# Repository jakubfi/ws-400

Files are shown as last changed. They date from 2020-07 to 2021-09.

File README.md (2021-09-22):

WS-400 is a device that connects to any of MERA-400 debug interfaces to display internal CPU and AWP states. You can see it in action [here](https://www.youtube.com/watch?v=3XAOpLWKt_o)

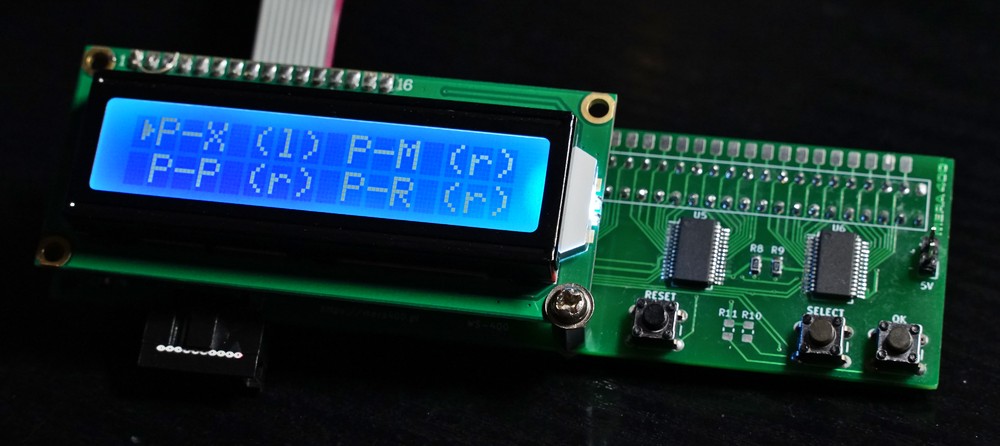
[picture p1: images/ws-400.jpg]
WS-400


After powering the device on, user selects the debug interface which WS-400 is connected to with *SELECT* button. Available connections are:

* **CPU**: P-X (l), P-M (r), P-P (r), P-R (r), P-A (l),
* **AWP**: FPA (l) FPA (r), FPM (l), FPM (r), FPS (l).

Connector location (either left or right) is denoted in parentheses. Selection is confirmed with *OK* button and WS-400 immediately starts displaying active signals. If all active signals don't fit on the screen, right pointing arrow appears on the bottom right. *SELECT* button can then be used to switch to next portion of active signals.

User can also switch to raw display mode at any time with *OK* button. In this mode *SELECT* button allows switching between 16-bit portions of the interface view.

Device can also be installed on the interface rotated 180 degrees in Z axis. This requires translation of signal, which is achieved by powering on or resetting the device with button *OK* pressed.

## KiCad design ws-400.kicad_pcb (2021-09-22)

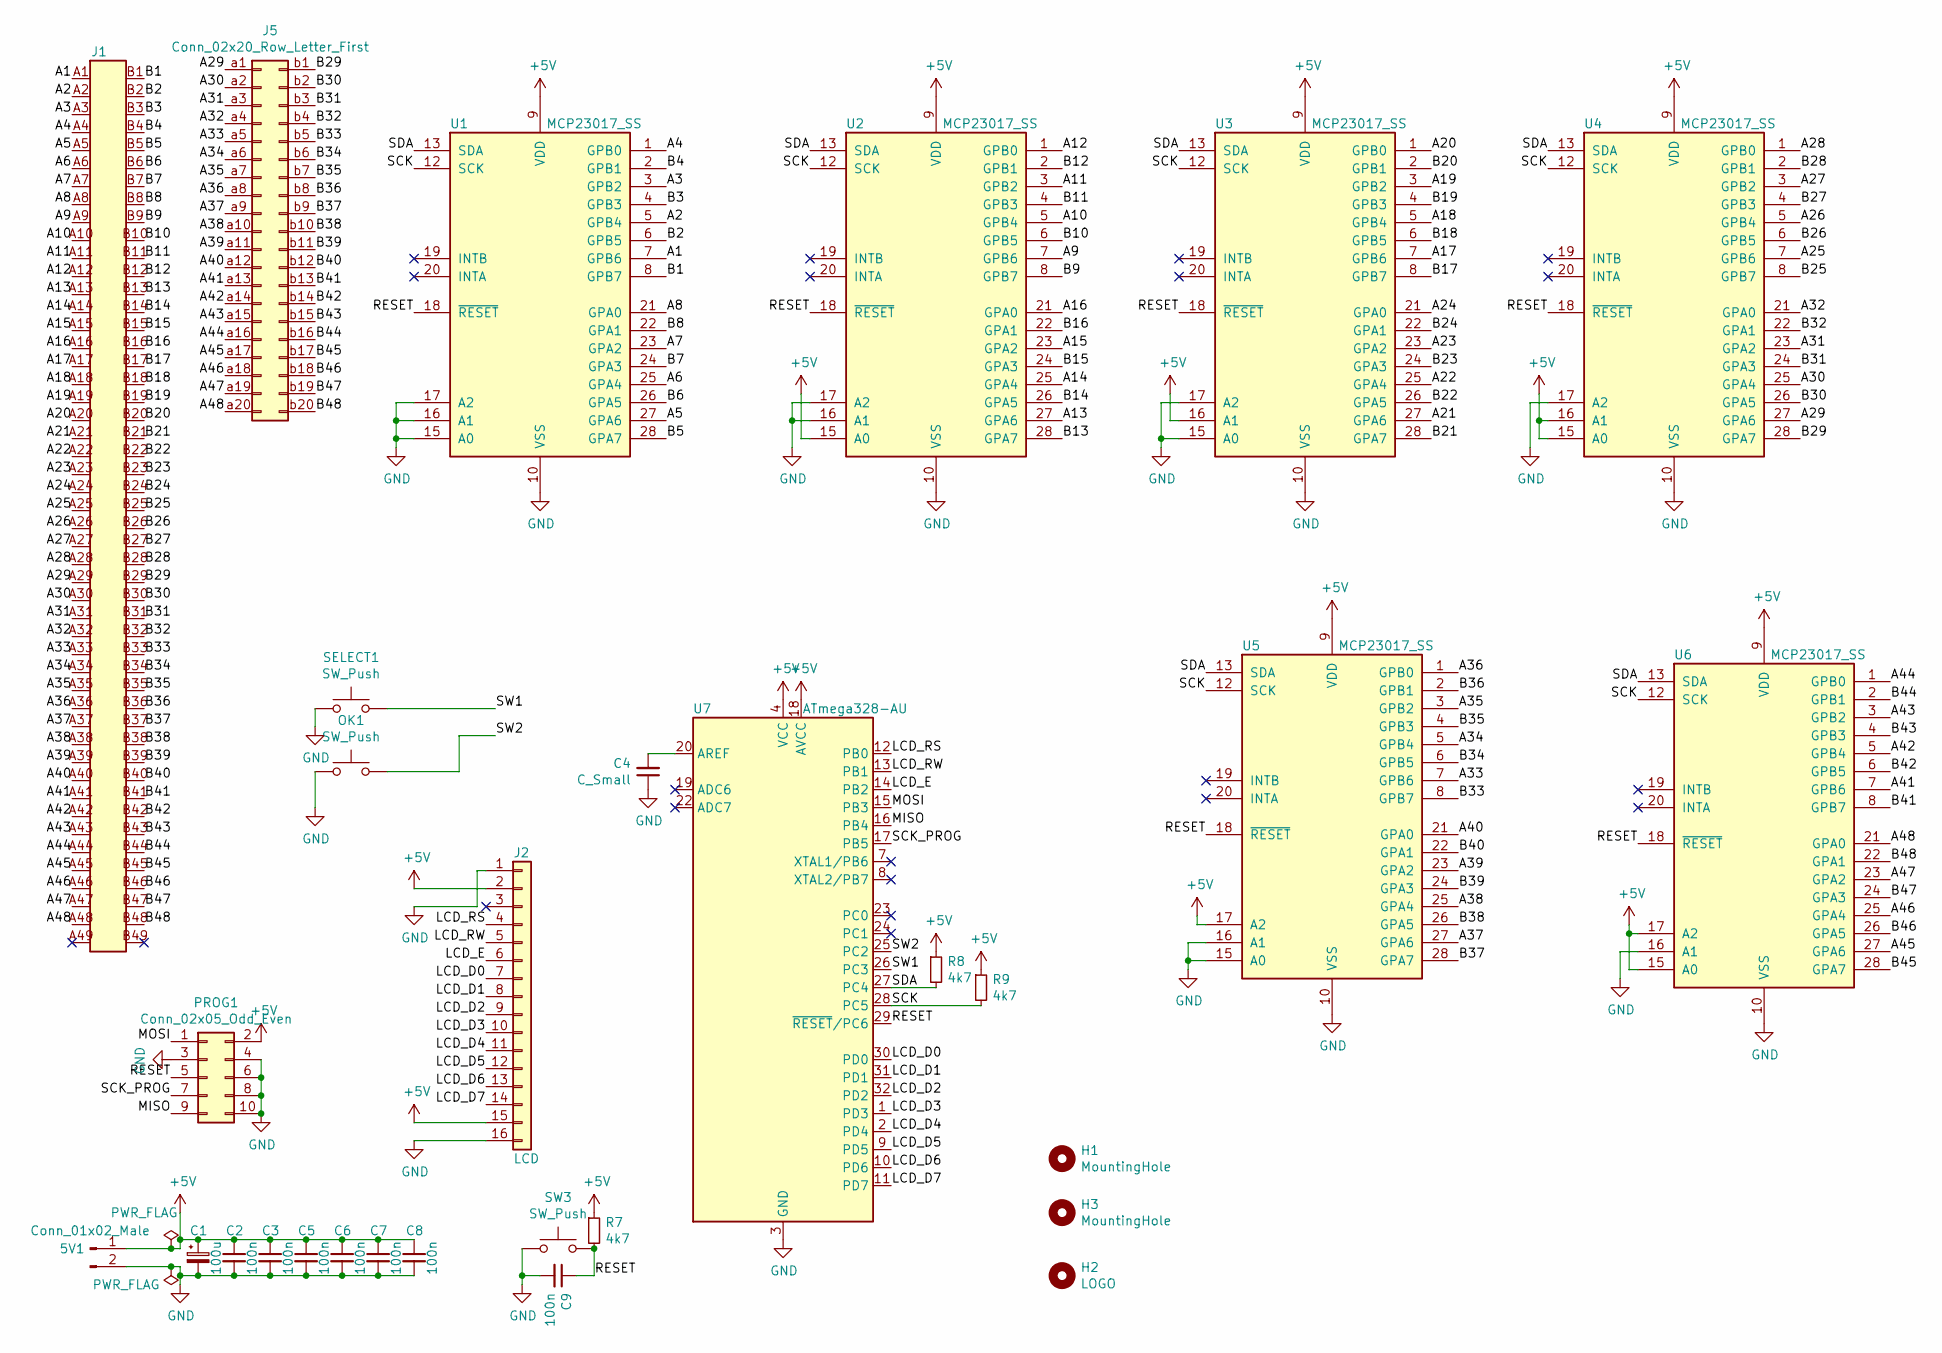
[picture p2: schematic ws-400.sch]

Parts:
5V1: Conn_01x02_Male; PinHeader_1x02_P2.54mm_Vertical
C1: 100u; CP_EIA-3528-21_Kemet-B_Pad1.50x2.35mm_HandSolder
C2, C3, C5, C6, C7, C8, C9: 100n; C_0805_2012Metric_Pad1.15x1.40mm_HandSolder
C4: C_Small; C_0805_2012Metric_Pad1.15x1.40mm_HandSolder
H1, H3: MountingHole; MountingHole_3mm
H2: LOGO; MERA400_LOGO_FCU_MEDIUM
J1: Conn_02x49; ELTRA801+
J2: LCD; PinHeader_1x16_P2.54mm_Vertical
J5: Conn_02x20_Row_Letter_First; 40pin_edge
OK1: SW_Push; SW_PUSH_6mm
PROG1: Conn_02x05_Odd_Even; PinHeader_2x05_P2.54mm_Vertical
R7, R8, R9: 4k7; R_0805_2012Metric_Pad1.15x1.40mm_HandSolder
SELECT1: SW_Push; SW_PUSH_6mm
SW3: SW_Push; SW_PUSH_6mm
U1, U2, U3, U4, U5, U6: MCP23017_SS; SSOP-28_5.3x10.2mm_P0.65mm
U7: ATmega328-AU; TQFP-32_7x7mm_P0.8mm

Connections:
+5V: 5V1.1, C1.1, C2.1, C3.1, C5.1, C6.1, C7.1, C8.1, J2.2, J2.15, PROG1.2, R7.1, R8.1, R9.1, U1.9 (VDD), U2.9 (VDD), U2.15 (A0), U3.9 (VDD), U3.16 (A1), U4.9 (VDD), U4.15 (A0), U4.16 (A1), U5.9 (VDD), U5.17 (A2), U6.9 (VDD), U6.15 (A0), U6.17 (A2), U7.4 (VCC), U7.6 (VCC), U7.18 (AVCC)
/A1: J1.A1, U1.7 (GPB6)
/A2: J1.A2, U1.5 (GPB4)
/A3: J1.A3, U1.3 (GPB2)
/A4: J1.A4, U1.1 (GPB0)
/A5: J1.A5, U1.27 (GPA6)
/A6: J1.A6, U1.25 (GPA4)
/A7: J1.A7, U1.23 (GPA2)
/A8: J1.A8, U1.21 (GPA0)
/A9: J1.A9, U2.7 (GPB6)
/A10: J1.A10, U2.5 (GPB4)
/A11: J1.A11, U2.3 (GPB2)
/A12: J1.A12, U2.1 (GPB0)
/A13: J1.A13, U2.27 (GPA6)
/A14: J1.A14, U2.25 (GPA4)
/A15: J1.A15, U2.23 (GPA2)
/A16: J1.A16, U2.21 (GPA0)
/A17: J1.A17, U3.7 (GPB6)
/A18: J1.A18, U3.5 (GPB4)
/A19: J1.A19, U3.3 (GPB2)
/A20: J1.A20, U3.1 (GPB0)
/A21: J1.A21, U3.27 (GPA6)
/A22: J1.A22, U3.25 (GPA4)
/A23: J1.A23, U3.23 (GPA2)
/A24: J1.A24, U3.21 (GPA0)
/A25: J1.A25, U4.7 (GPB6)
/A26: J1.A26, U4.5 (GPB4)
/A27: J1.A27, U4.3 (GPB2)
/A28: J1.A28, U4.1 (GPB0)
/A29: J1.A29, J5.a1, U4.27 (GPA6)
/A30: J1.A30, J5.a2, U4.25 (GPA4)
/A31: J1.A31, J5.a3, U4.23 (GPA2)
/A32: J1.A32, J5.a4, U4.21 (GPA0)
/A33: J1.A33, J5.a5, U5.7 (GPB6)
/A34: J1.A34, J5.a6, U5.5 (GPB4)
/A35: J1.A35, J5.a7, U5.3 (GPB2)
/A36: J1.A36, J5.a8, U5.1 (GPB0)
/A37: J1.A37, J5.a9, U5.27 (GPA6)
/A38: J1.A38, J5.a10, U5.25 (GPA4)
/A39: J1.A39, J5.a11, U5.23 (GPA2)
/A40: J1.A40, J5.a12, U5.21 (GPA0)
/A41: J1.A41, J5.a13, U6.7 (GPB6)
/A42: J1.A42, J5.a14, U6.5 (GPB4)
/A43: J1.A43, J5.a15, U6.3 (GPB2)
/A44: J1.A44, J5.a16, U6.1 (GPB0)
/A45: J1.A45, J5.a17, U6.27 (GPA6)
/A46: J1.A46, J5.a18, U6.25 (GPA4)
/A47: J1.A47, J5.a19, U6.23 (GPA2)
/A48: J1.A48, J5.a20, U6.21 (GPA0)
/B1: J1.B1, U1.8 (GPB7)
/B2: J1.B2, U1.6 (GPB5)
/B3: J1.B3, U1.4 (GPB3)
/B4: J1.B4, U1.2 (GPB1)
/B5: J1.B5, U1.28 (GPA7)
/B6: J1.B6, U1.26 (GPA5)
/B7: J1.B7, U1.24 (GPA3)
/B8: J1.B8, U1.22 (GPA1)
/B9: J1.B9, U2.8 (GPB7)
/B10: J1.B10, U2.6 (GPB5)
/B11: J1.B11, U2.4 (GPB3)
/B12: J1.B12, U2.2 (GPB1)
/B13: J1.B13, U2.28 (GPA7)
/B14: J1.B14, U2.26 (GPA5)
/B15: J1.B15, U2.24 (GPA3)
/B16: J1.B16, U2.22 (GPA1)
/B17: J1.B17, U3.8 (GPB7)
/B18: J1.B18, U3.6 (GPB5)
/B19: J1.B19, U3.4 (GPB3)
/B20: J1.B20, U3.2 (GPB1)
/B21: J1.B21, U3.28 (GPA7)
/B22: J1.B22, U3.26 (GPA5)
/B23: J1.B23, U3.24 (GPA3)
/B24: J1.B24, U3.22 (GPA1)
/B25: J1.B25, U4.8 (GPB7)
/B26: J1.B26, U4.6 (GPB5)
/B27: J1.B27, U4.4 (GPB3)
/B28: J1.B28, U4.2 (GPB1)
/B29: J1.B29, J5.b1, U4.28 (GPA7)
/B30: J1.B30, J5.b2, U4.26 (GPA5)
/B31: J1.B31, J5.b3, U4.24 (GPA3)
/B32: J1.B32, J5.b4, U4.22 (GPA1)
/B33: J1.B33, J5.b5, U5.8 (GPB7)
/B34: J1.B34, J5.b6, U5.6 (GPB5)
/B35: J1.B35, J5.b7, U5.4 (GPB3)
/B36: J1.B36, J5.b8, U5.2 (GPB1)
/B37: J1.B37, J5.b9, U5.28 (GPA7)
/B38: J1.B38, J5.b10, U5.26 (GPA5)
/B39: J1.B39, J5.b11, U5.24 (GPA3)
/B40: J1.B40, J5.b12, U5.22 (GPA1)
/B41: J1.B41, J5.b13, U6.8 (GPB7)
/B42: J1.B42, J5.b14, U6.6 (GPB5)
/B43: J1.B43, J5.b15, U6.4 (GPB3)
/B44: J1.B44, J5.b16, U6.2 (GPB1)
/B45: J1.B45, J5.b17, U6.28 (GPA7)
/B46: J1.B46, J5.b18, U6.26 (GPA5)
/B47: J1.B47, J5.b19, U6.24 (GPA3)
/B48: J1.B48, J5.b20, U6.22 (GPA1)
/LCD_D0: J2.7, U7.30 (PD0)
/LCD_D1: J2.8, U7.31 (PD1)
/LCD_D2: J2.9, U7.32 (PD2)
/LCD_D3: J2.10, U7.1 (PD3)
/LCD_D4: J2.11, U7.2 (PD4)
/LCD_D5: J2.12, U7.9 (PD5)
/LCD_D6: J2.13, U7.10 (PD6)
/LCD_D7: J2.14, U7.11 (PD7)
/LCD_E: J2.6, U7.14 (PB2)
/LCD_RS: J2.4, U7.12 (PB0)
/LCD_RW: J2.5, U7.13 (PB1)
/MISO: PROG1.9, U7.16 (PB4)
/MOSI: PROG1.1, U7.15 (PB3)
/RESET: C9.1, PROG1.5, R7.2, SW3.2, U1.18 (~RESET~), U2.18 (~RESET~), U3.18 (~RESET~), U4.18 (~RESET~), U5.18 (~RESET~), U6.18 (~RESET~), U7.29 (~RESET~/PC6)
/SCK: R9.2, U1.12 (SCK), U2.12 (SCK), U3.12 (SCK), U4.12 (SCK), U5.12 (SCK), U6.12 (SCK), U7.28 (PC5)
/SCK_PROG: PROG1.7, U7.17 (PB5)
/SDA: R8.2, U1.13 (SDA), U2.13 (SDA), U3.13 (SDA), U4.13 (SDA), U5.13 (SDA), U6.13 (SDA), U7.27 (PC4)
/SW1: SELECT1.2, U7.26 (PC3)
/SW2: OK1.2, U7.25 (PC2)
GND: 5V1.2, C1.2, C2.2, C3.2, C4.1, C5.2, C6.2, C7.2, C8.2, C9.2, J2.1, J2.16, OK1.1, PROG1.3, PROG1.4, PROG1.6, PROG1.8, PROG1.10, SELECT1.1, SW3.1, U1.10 (VSS), U1.15 (A0), U1.16 (A1), U1.17 (A2), U2.10 (VSS), U2.16 (A1), U2.17 (A2), U3.10 (VSS), U3.15 (A0), U3.17 (A2), U4.10 (VSS), U4.17 (A2), U5.10 (VSS), U5.15 (A0), U5.16 (A1), U6.10 (VSS), U6.16 (A1), U7.3 (GND), U7.5 (GND), U7.21 (GND)
unnamed: C4.2, U7.20 (AREF)

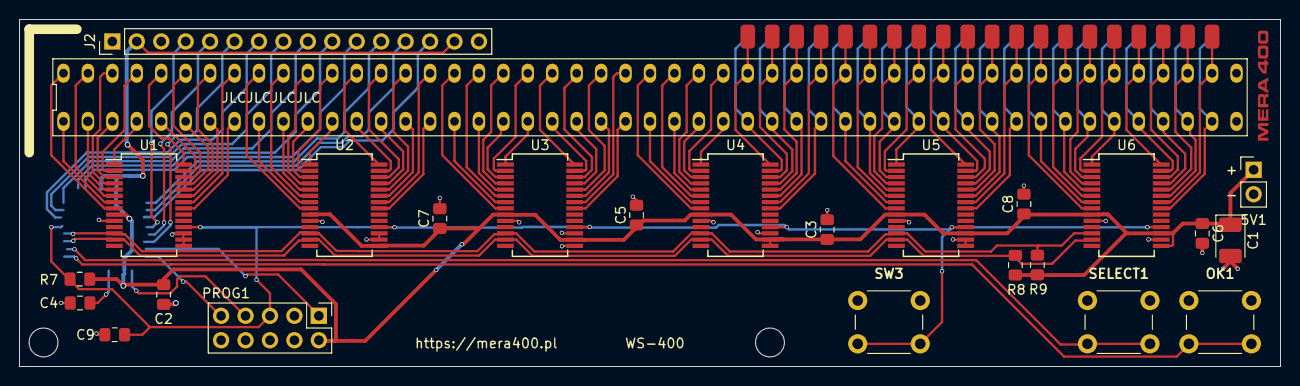
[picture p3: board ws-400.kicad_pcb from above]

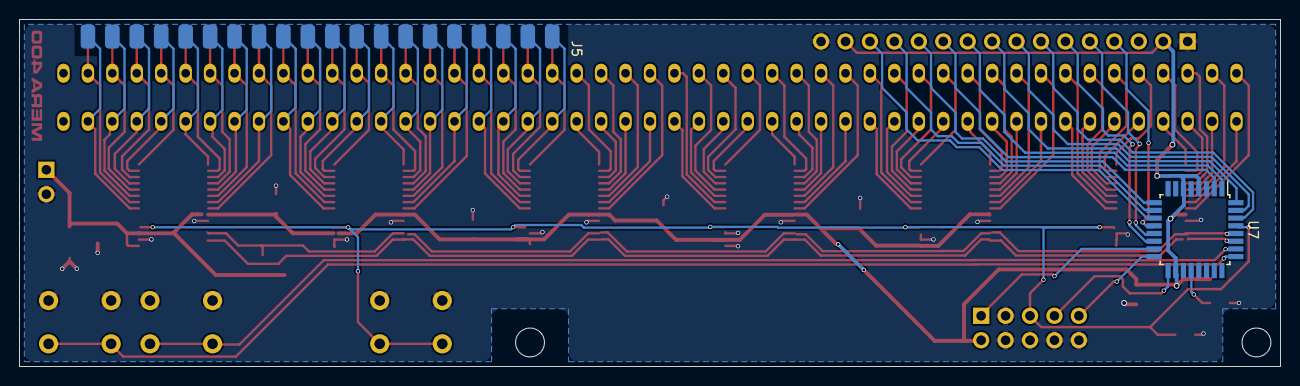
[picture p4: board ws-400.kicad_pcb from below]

Board: 2 copper layers, 131.1 x 36.1 mm, 30 parts (2 on the bottom side), 118 nets.

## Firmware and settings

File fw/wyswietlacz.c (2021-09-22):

#include <stdint.h>
#include <stdlib.h>
#include <stddef.h>
#include <stdio.h>
#include <string.h>
#include <avr/io.h>
#include <util/delay.h>
#include "hd44780.h"
#include "mcp23017.h"
#include "i2cmaster.h"
#include "chars.h"
#include "pins.h"
#include "scr.h"

#define SW_DIR	DDRC
#define SW_PORT	PORTC
#define SW_PIN	PINC
#define SW_SEL	(1 << PC3)
#define SW_OK	(1 << PC2)

MCP23017 dev[6];

/*
 * There are two debugger connectors per each module. This device can be connected to any one of them.
 * Each connector is a 96-pin edge connector. Pins are numbered from the right, starting from 1.
 * Top row is "D" row, bottom is "C". Right connector has pins 1 to 48, left - 49 to 96.
 *
 * Port expanders on the device are connected as follows:
 *
 *       1B7 1B5 1B3       6A5 6A3 6A1
 *     .-------------\   \------------.
 *     | D48 D47 D46 /   / D2  D1  D0 |
 *     | C48 C47 C46 \   \ C2  C1  C0 |
 *     `-------------/   /------------'
 *       1B6 1B4 1B2       6A4 6A2 6A0
 *
 * Note: "1B7" = expander U1, port B, bit 7
 *
 * When connecting the device to the left port, pin numbers 49-96 are remapped to 1-48
*/

uint8_t rotated = 0;
uint16_t raw_data[6];

// -----------------------------------------------------------------------
void update_state(void)
{
#ifdef SIMULATED
	static const uint16_t sim_data[6] = {
		0b0000000000000000,
		0b0000000000000000,
		0b0000000100000000,
		0b0000000010000000,
		0b0000000000000000,
		0b0000000000000000,
	};
	#endif

	for (uint8_t i=0 ; i<6 ; i++) {
#ifdef SIMULATED
		raw_data[i] = sim_data[i];
#else
		raw_data[i]  = mcp23017_read_register(dev+i, MCP23017_GPIOB) << 8;
		raw_data[i] |= mcp23017_read_register(dev+i, MCP23017_GPIOA);
#endif
	}
}

// -----------------------------------------------------------------------
uint8_t read_signal(uint8_t row, uint8_t column)
{
	// Device connects to either right (pins 1-48) or left (pins 49-96) debug connector.
	// Translate row numbers to 1-48 for the left connector.
	if (column > 48) column = column - 48;

	// Pins are numbered right to left, 1 to 48. Bits are stored left to right.
	// Column numbers need to be swapped and reindexed: 1..48 -> 47..0
	column = 48 - column;

	// Translate row and column if the device is rotated.
	if (rotated) {
		column = 47 - column; // first column becomes last
		row = 1 - row; // top row becomes bottom
	}

	// Each word holds 8 columns of data
	const uint8_t word = column / 8;
	// 2 bits per column, 16 bits per word
	// upper row holds even bits (with no rotation)
	const uint8_t bit = 15 - (2 * (column % 8) + row);

	return (raw_data[word] >> bit) & 1;
}

// -----------------------------------------------------------------------
uint8_t read_signal_rowcol(uint8_t rowcol)
{
	const uint8_t row = rowcol >> 7;
	const uint8_t col = rowcol & 0b01111111;

	return read_signal(row, col);
}


// -----------------------------------------------------------------------
void print_raw(uint8_t pos)
{
	const int8_t columns = 8;
	const int8_t start = 1 + columns * pos;
	const int8_t end = start + columns;
	char s[12];

	scr_clr();

	sprintf(s, "%d-%d", end-1, start);
	scr_print_at(11, 0, " pos");
	scr_print_at(11, 1, s);
	scr_put_at(10, 0, CH_VDOT);
	scr_put_at(10, 1, CH_VDOT);

	uint8_t xpos = 8;
	for (uint8_t column=start ; column<end ; column++) {
		for (uint8_t row=ROW_D ; row<=ROW_C ; row++) {
			const uint8_t val = '0' + read_signal(row, column);
			scr_put_at(xpos, row, val);
		}
		xpos--;
		if (xpos == 4) xpos--; // additional space between nibbles
	}
}

// -----------------------------------------------------------------------
char * decimalize(const __flash struct signal *s, char *tmp, uint8_t polarity)
{
	int8_t *x = (int8_t*) s->d.reg;
	// Value may require shifting left if it is a part of larger register.
	// Shift is stored in the attributes.
	const uint8_t shift = (s->attr & SIG_SHIFT_MASK) >> SIG_SHIFT_POS;

	uint16_t val = 0;
	while (*x != 0) {
		val <<= 1;
		if (read_signal_rowcol(*x) == polarity) val |= 1;
		x++;
	}

	sprintf(tmp, "%s=%ld", s->name, ((uint32_t)val) << shift);

	return tmp;
}

// -----------------------------------------------------------------------
int smart_print(char *str)
{
	if (!str) return 0;

	const uint8_t len = strlen(str);
	if (sx+len > LCD_COLS-sy) { // -sy to make space for CH_CONT at line 1
		if (sy >= 1) {
			scr_put_at(15, 1, CH_CONT);
			return 1;
		} else {
			scr_setpos(0, 1);
		}
	}

	scr_print(str);
	if ((sx > 0) && (sx < LCD_COLS)) {
		scr_print(" ");
	}
	return 0;
}

// -----------------------------------------------------------------------
const struct signal * print_state(const __flash struct signal *s)
{
	char *str;
	char tmp[16];
	uint8_t no_fit = 0;

	scr_clr();

	while (s->name) {
		const uint8_t sig_polarity = s->attr & SIG_POLARITY_MASK;
		const uint8_t sig_type = s->attr & SIG_TYPE_MASK;

		str = NULL;
		if (sig_type == BIN) {
			if (read_signal_rowcol(s->d.rowcol) == sig_polarity) str = (char *) s->name;
		} else if (sig_type == DEC) {
			str = decimalize(s, tmp, sig_polarity);
		}

		no_fit = smart_print(str);
		if (no_fit) {
			break;
		} else {
			s++;
		}
	}

	if (!s->name) s = NULL;

	return s;
}

// -----------------------------------------------------------------------
void menu_update(uint8_t pos)
{
	static uint8_t last_pos = 99;
	if (last_pos == pos) return;
	last_pos = pos;

	static const char *conns[] = {
		" P-X (l)",
		" P-M (r)",
		" P-P (r)",
		" P-R (r)",
		" P-A (l)",
		" FPA (l)",
		" FPA (r)",
		" FPM (l)",
		" FPM (r)",
		" FPS (l)",
		"\x02\x02\x02\x02\x02\x02\x02\x02",
		"\x02\x02\x02\x02\x02\x02\x02\x02",
		NULL
	};

	const uint8_t start_p = 4*(pos / 4);
	const uint8_t end_p = start_p + 4;

	scr_clr();

	for (uint8_t i=start_p ; i<end_p ; i++) {
		scr_print(conns[i]);
	}

	const uint8_t cpos = pos % 4;
	scr_put_at(8*(cpos%2), cpos/2, CH_CURSOR);

	scr_blit();
}

// -----------------------------------------------------------------------
uint8_t key_pressed(uint8_t expected_key)
{
	uint8_t shift_reg = 0;
	int8_t repetitions = 0;

	do {
		shift_reg |= (SW_PIN & expected_key) ? 0 : 1;
		if ((repetitions == 0) && (shift_reg == 0)) {
			// no initial key press, nothing to do
			return 0;
		} else if (shift_reg == 0xff) {
			// got a key press
			return 1;
		} else {
			// press detected, start debouncing
			shift_reg <<= 1;
			repetitions++;
			_delay_ms(4);
		}
	} while (repetitions < 40);

	// no keypress after N repetitions
	return 0;
}

// -----------------------------------------------------------------------
void wait_no_key(void)
{
	while ((SW_PIN & (SW_SEL|SW_OK)) != (SW_SEL|SW_OK));
}

// -----------------------------------------------------------------------
const struct signal * select_connector()
{
	const uint8_t CONN_COUNT = 10;
	const struct signal *connections[] = { PX, PM, PP, PR, PA, FPAL, FPAR, FPML, FPMR, FPS };

	uint8_t pos = 0;

	menu_update(0);

	while (1) {
		if (key_pressed(SW_OK)) {
			wait_no_key();
			break;
		} else if (key_pressed(SW_SEL)) {
			pos++;
			if (pos >= CONN_COUNT) {
				pos = 0;
			}
			menu_update(pos);
			wait_no_key();
		}
	}

	return connections[pos];
}

// -----------------------------------------------------------------------
void setup()
{
	// setup switches
	SW_DIR &= ~(SW_SEL|SW_OK);
	SW_PORT |= (SW_SEL|SW_OK);

	// setup MCP23017
	for (uint8_t i=0 ; i<6 ; i++) {
		mcp23017_init(dev+i, i);
		mcp23017_write_register(dev+i, MCP23017_IODIRA, 0xff);
		mcp23017_write_register(dev+i, MCP23017_IODIRB, 0xff);
		mcp23017_write_register(dev+i, MCP23017_IPOLA, 0);
		mcp23017_write_register(dev+i, MCP23017_IPOLB, 0);
		mcp23017_write_register(dev+i, MCP23017_GPPUA, 0);
		mcp23017_write_register(dev+i, MCP23017_GPPUB, 0);
	}

	// setup LCD
	lcd_init();
	lcd_cg_set(CH_CURSOR, cursor);
	lcd_cg_set(CH_HDOT, hdot);
	lcd_cg_set(CH_VDOT, vdot);
	lcd_cg_set(CH_CONT, cont);
	lcd_clear();
	lcd_home();
}

// -----------------------------------------------------------------------
int select_rotation(void)
{
	// If started with "OK" button pressed, assume display rotated 180 deg.
	if (!key_pressed(SW_OK)) return 0;

	scr_print_at(1, 0, ".-  DEVICE  <-.");
	scr_print_at(1, 1, "`>  ROTATED  -'");
	scr_blit();
	_delay_ms(500);
	wait_no_key();

	return 1;
}

// -----------------------------------------------------------------------
// ---- MAIN -------------------------------------------------------------
// -----------------------------------------------------------------------
int main(void)
{
	uint8_t raw = 0;
	uint8_t raw_pos = 0;
	uint8_t key_was_pressed = 0;
	const struct signal *selected_connector;
	const __flash struct signal *start_signal;
	const __flash struct signal *next_signal = NULL;

	setup();
	scr_clr();

	rotated = select_rotation();
	selected_connector = select_connector();
	start_signal = selected_connector;

	while (1) {
		// read debug bus state
		update_state();

		// Handle selecting next portion of signals (if they don't fit on the screen)
		if (key_pressed(SW_SEL)) {
			key_was_pressed = 1;
			if (raw) {
				raw_pos++;
				if (raw_pos>5) raw_pos = 0;
			} else {
				if (next_signal) start_signal = next_signal;
				else start_signal = selected_connector;
			}
		}

		// Pressing "OK" switches between raw and normal display
		if (key_pressed(SW_OK)) {
			key_was_pressed = 1;
			raw = ~raw;
			start_signal = selected_connector;
		}

		// Update screen immediatly after a key press for nice interactivity
		// (don't wait for key depress).
		if (raw) {
			print_raw(raw_pos);
		} else {
			next_signal = print_state(start_signal);
		}
		scr_blit();

		// Wait for key depress only if a key was pressed in current loop
		// so we don't wait if a key was pressed during screen update.
		// That's to avoid ghost presses.
		if (key_was_pressed) {
			key_was_pressed = 0;
			wait_no_key();
		}
	}
}

// vim: tabstop=4 shiftwidth=4 autoindent

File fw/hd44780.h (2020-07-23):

#ifndef __HD44780_H_
#define __HD44780_H_

#include <avr/io.h>

#define LCD_COLS 16
#define LCD_LINES 2

// --- port setup --------------------------------------------------------

#define LCD_RS_DIR	DDRB
#define LCD_RS_PORT	PORTB
#define LCD_RS		(1 << PB0)

#define LCD_RW_DIR	DDRB
#define LCD_RW_PORT	PORTB
#define LCD_RW		(1 << PB1)

#define LCD_E_DIR	DDRB
#define LCD_E_PORT	PORTB
#define LCD_E		(1 << PB2)

#define LCD_DATA_DIR	DDRD
#define LCD_DATA_PORT	PORTD
#define LCD_DATA_PIN	PIND

// --- HD44780 commands --------------------------------------------------

#define HD44780_CLEAR			0x01
#define HD44780_HOME			0x02
#define HD44780_ENTRY_MODE		0x04
#define HD44780_DISPLAY			0x08
#define HD44780_SHIFT			0x10
#define HD44780_FUNCTION		0x20
#define HD44780_CGRAM_ADDR		0x40
#define HD44780_DDRAM_ADDR		0x80

#define HD44780_EM_SHIFT_RIGHT	0 << 0
#define HD44780_EM_SHIFT_LEFT	1 << 0
#define HD44780_EM_NOSHIFT		0 << 1
#define HD44780_EM_SHIFT		1 << 1

#define HD44780_BLINK_OFF		0 << 0
#define HD44780_BLINK_ON		1 << 0
#define HD44780_CURSOR_OFF		0 << 1
#define HD44780_CURSOR_ON		1 << 1
#define HD44780_DISPLAY_OFF		0 << 2
#define HD44780_DISPLAY_ON		1 << 2

#define HD44780_SHIFT_LEFT		0 << 2
#define HD44780_SHIFT_RIGHT		1 << 2
#define HD44780_SHIFT_CURSOR	0 << 3
#define HD44780_SHIFT_DISPLAY	1 << 3

#define HD44780_FONT5x7			0 << 2
#define HD44780_FONT5x10		1 << 2
#define HD44780_ONE_LINE		0 << 3
#define HD44780_TWO_LINES		1 << 3
#define HD44780_4_BIT			0 << 4
#define HD44780_8_BIT			1 << 4

void lcd_write_cmd(const uint8_t cmd);
void lcd_write_data(const uint8_t data);
unsigned char lcd_read_data(void);
void lcd_puts(const char *str, int8_t len);
void lcd_print(const char *);
void lcd_setpos(const uint8_t x, const uint8_t y);
void lcd_clear(void);
void lcd_home(void);
void lcd_cg_set(const uint8_t ch, const __flash uint8_t *chdata);
void lcd_init(void);
uint8_t lcd_get_x();
uint8_t lcd_get_y();

#endif

// vim: tabstop=4 shiftwidth=4 autoindent

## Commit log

2020-07-23 raw print fixes
2020-12-30 fixes:
    * shift partial decimal values
    * swap FPA/FPM
    * fix FIC order
    [wyswietlacz.c]
2021-09-20 pins rework
    * introduce pin attributes
    * simplify print type selection logic
    * fix some pins polarity
    * add missinf pins
    [wyswietlacz.c]
2021-09-21 make print_raw() work again
2021-09-22 rework signal mapping logic
    [wyswietlacz.c]
2021-09-22 compact pin tables by unionizing fields, fix register terminators
    [wyswietlacz.c]
2021-09-22 add Kicad files
    [ws-400.kicad_pcb, ws-400.sch]
2021-09-22 schematic cleanup
    [ws-400.kicad_pcb, ws-400.sch]
